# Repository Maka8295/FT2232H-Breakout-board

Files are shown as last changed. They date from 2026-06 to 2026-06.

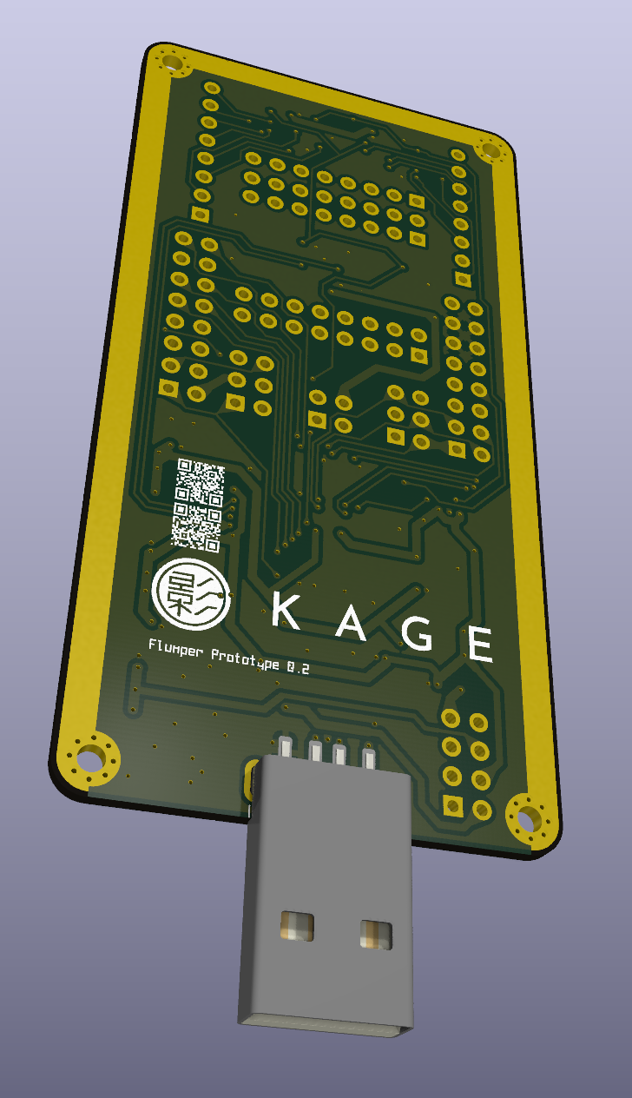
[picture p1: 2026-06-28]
flash2.png

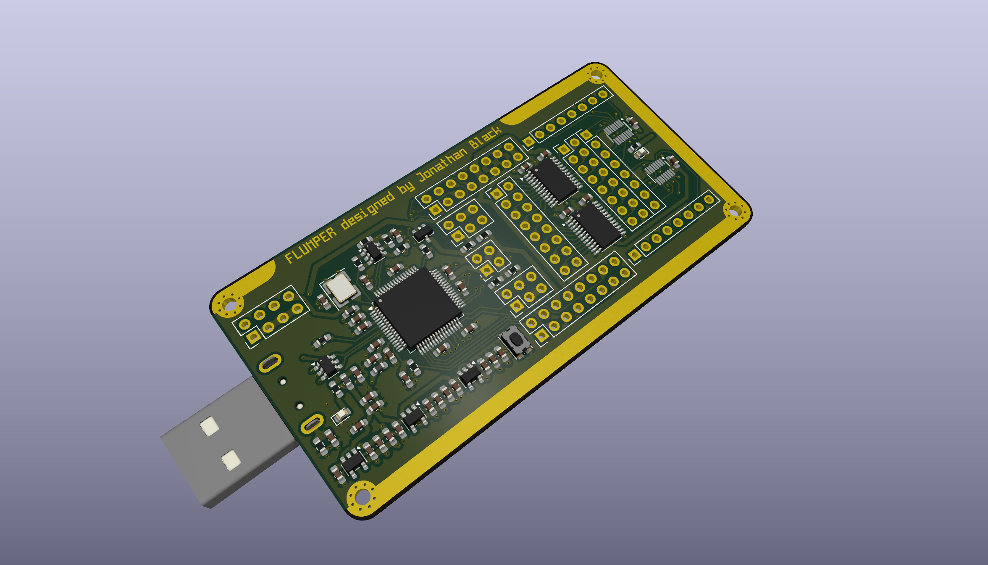
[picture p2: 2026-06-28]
flash.png

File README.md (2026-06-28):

# Bill of Materials

**Line items:** 28  |  **Total components:** 70

> Pin header connectors (J2–J12) are excluded from this BOM.

## IC

| Designator | Value / Part | Footprint | Qty |
|---|---|---|---|
| U1 | LDK130M18R | `SOT-23-5` | 1 |
| U2 | LDK130M25R | `SOT-23-5` | 1 |
| U3 | AP2112K-3.3 | `SOT-23-5` | 1 |
| U4 | USBLC6-2SC6 | `SOT-23-6` | 1 |
| U5 | 93LCxxBxxOT | `SOT-23-6` | 1 |
| U6 | FT2232HL | `LQFP-64_10x10mm_P0.5mm` | 1 |
| U7, U8 | TMUX1574DYY | `Texas_DYY0016A_TSOT-23-16_2x4.2mm_P0.5mm` | 2 |
| U9, U10 | SN74LVC8T245PWR | `TSSOP-24_4.4x7.8mm_P0.65mm` | 2 |

## Connector

| Designator | Value / Part | Footprint | Qty |
|---|---|---|---|
| J1 | USB_A | `USB_A_CNCTech_1001-011-01101_Horizontal` | 1 |

## Resistor

| Designator | Value / Part | Footprint | Qty |
|---|---|---|---|
| R1 | 2.2k | `R_0603_1608Metric_Pad0.98x0.95mm` | 1 |
| R2, R3, R5 | 1k | `R_0603_1608Metric_Pad0.98x0.95mm` | 3 |
| R4 | 1M | `R_0603_1608Metric_Pad0.98x0.95mm` | 1 |
| R6 | 12k/1% | `R_0603_1608Metric_Pad0.98x0.95mm` | 1 |
| R7, R8, R9, R10 | 4.7k | `R_0603_1608Metric_Pad0.98x0.95mm` | 4 |
| R11, R12, R13 | 10k | `R_0603_1608Metric_Pad0.98x0.95mm` | 3 |
| R14 | 2k | `R_0603_1608Metric_Pad0.98x0.95mm` | 1 |

## Capacitor

| Designator | Value / Part | Footprint | Qty |
|---|---|---|---|
| C1, C2, C3, C4, C5, C6 | 1uF | `C_0603_1608Metric_Pad1.08x0.95mm` | 6 |
| C7 | 2.2nF | `C_0603_1608Metric_Pad1.08x0.95mm` | 1 |
| C8, C10 | 10nF | `C_0603_1608Metric_Pad1.08x0.95mm` | 2 |
| C9 | 100nF | `C_0603_1608Metric_Pad1.08x0.95mm` | 1 |
| C11, C12, C13, C14, C15, C18, C19, C20, C22, C24, C27, C28, C29, C31, C33, C34, C35, C36, C37, C39 | 0.1uF | `C_0603_1608Metric_Pad1.08x0.95mm` | 20 |
| C16 | 0.01uF | `C_0603_1608Metric_Pad1.08x0.95mm` | 1 |
| C17, C21, C23, C30, C32, C38 | 4.7uF | `C_0603_1608Metric_Pad1.08x0.95mm` | 6 |

## Inductor

| Designator | Value / Part | Footprint | Qty |
|---|---|---|---|
| L1, L2, L3 | 600R/0.5A | `L_0603_1608Metric_Pad1.05x0.95mm` | 3 |

## Transistor/MOSFET

| Designator | Value / Part | Footprint | Qty |
|---|---|---|---|
| Q1 | AO3400A | `SOT-23` | 1 |

## LED

| Designator | Value / Part | Footprint | Qty |
|---|---|---|---|
| D1, D2 | LED | `LED_0603_1608Metric` | 2 |

## Crystal

| Designator | Value / Part | Footprint | Qty |
|---|---|---|---|
| Y1 | SCTF SX3M12.000M20F30TNN | `Crystal_SMD_3225-4Pin_3.2x2.5mm_HandSoldering` | 1 |

## Switch

| Designator | Value / Part | Footprint | Qty |
|---|---|---|---|
| SW1 | Reset Button | `SW_Push_1P1T_NO_CK_KMR2` | 1 |

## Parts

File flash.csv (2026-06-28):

Id | Designator | Footprint | Quantity | Designation | Supplier and ref
1 | C1, C2, C3, C4, C5, C6 | C_0603_1608Metric_Pad1.08x0.95mm_HandSolder | 6 | 1uF
2 | C7 | C_0603_1608Metric_Pad1.08x0.95mm_HandSolder | 1 | 2.2nF
3 | C8, C10 | C_0603_1608Metric_Pad1.08x0.95mm_HandSolder | 2 | 10nF
4 | C9 | C_0603_1608Metric_Pad1.08x0.95mm_HandSolder | 1 | 100nF
5 | C11, C12, C13, C14, C15, C18, C19, C20, C22, C24, C27, C28, C29, C31, C33, C34, C35, C36, C37, C39 | C_0603_1608Metric_Pad1.08x0.95mm_HandSolder | 20 | 0.1uF
6 | C16 | C_0603_1608Metric_Pad1.08x0.95mm_HandSolder | 1 | 0.01uF
7 | C17, C21, C23, C30, C32, C38 | C_0603_1608Metric_Pad1.08x0.95mm_HandSolder | 6 | 4.7uF
8 | D1, D2 | LED_0603_1608Metric | 2 | LED
9 | J1 | USB_A_CNCTech_1001-011-01101_Horizontal | 1 | USB_A
10 | J2 | PinHeader_2x04_P2.54mm_Vertical | 1 | Conn_01x08_Pin
11 | J3, J4 | PinHeader_2x03_P2.54mm_Vertical | 2 | Conn_01x06_Pin
12 | J5 | PinHeader_2x02_P2.54mm_Vertical | 1 | Conn_01x04_Pin
13 | J6 | PinHeader_2x08_P2.54mm_Vertical | 1 | AOUT
14 | J7 | PinHeader_2x08_P2.54mm_Vertical | 1 | BOUT
15 | J8 | PinHeader_2x08_P2.54mm_Vertical | 1 | LSIN
16 | J9 | PinHeader_2x08_P2.54mm_Vertical | 1 | LSOUT
17 | J10 | PinHeader_1x08_P2.54mm_Vertical | 1 | TMIN
18 | J11 | PinHeader_1x08_P2.54mm_Vertical | 1 | TM1OUT
19 | J12 | PinHeader_1x08_P2.54mm_Vertical | 1 | TM2OUT
20 | L1, L2, L3 | L_0603_1608Metric_Pad1.05x0.95mm_HandSolder | 3 | 600R/0.5A
21 | Q1 | SOT-23 | 1 | AO3400A
22 | R1 | R_0603_1608Metric_Pad0.98x0.95mm_HandSolder | 1 | 2.2k
23 | R2, R3, R5 | R_0603_1608Metric_Pad0.98x0.95mm_HandSolder | 3 | 1k
24 | R4 | R_0603_1608Metric_Pad0.98x0.95mm_HandSolder | 1 | 1M
25 | R6 | R_0603_1608Metric_Pad0.98x0.95mm_HandSolder | 1 | 12k/1%
26 | R7, R8, R9, R10 | R_0603_1608Metric_Pad0.98x0.95mm_HandSolder | 4 | 4.7k
27 | R11, R12, R13 | R_0603_1608Metric_Pad0.98x0.95mm_HandSolder | 3 | 10k
28 | R14 | R_0603_1608Metric_Pad0.98x0.95mm_HandSolder | 1 | 2k
29 | SW1 | SW_Push_1P1T_NO_CK_KMR2 | 1 | Reset Button
30 | U1 | SOT-23-5 | 1 | LDK130M18R
31 | U2 | SOT-23-5 | 1 | LDK130M25R
32 | U3 | SOT-23-5 | 1 | AP2112K-3.3
33 | U4 | SOT-23-6 | 1 | USBLC6-2SC6
34 | U5 | SOT-23-6 | 1 | 93LCxxBxxOT
35 | U6 | LQFP-64_10x10mm_P0.5mm | 1 | FT2232HL
36 | U7, U8 | Texas_DYY0016A_TSOT-23-16_2x4.2mm_P0.5mm | 2 | TMUX1574DYY
37 | U9, U10 | TSSOP-24_4.4x7.8mm_P0.65mm | 2 | SN74LVC8T245PWR
38 | Y1 | Crystal_SMD_3225-4Pin_3.2x2.5mm_HandSoldering | 1 | SCTF SX3M12.000M20F30TNN

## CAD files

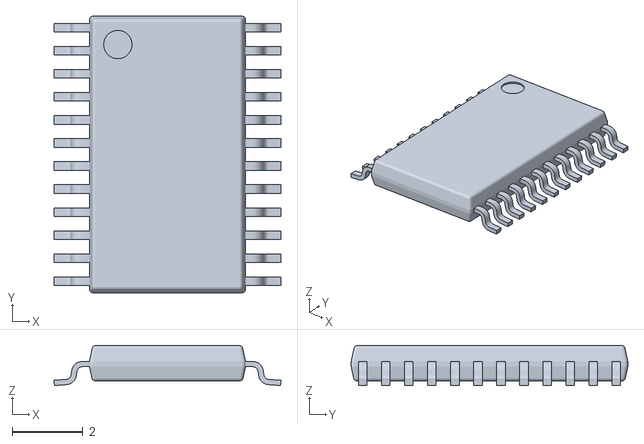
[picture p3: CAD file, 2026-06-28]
components/PW0024A.stl
6.40 x 7.80 x 1.13

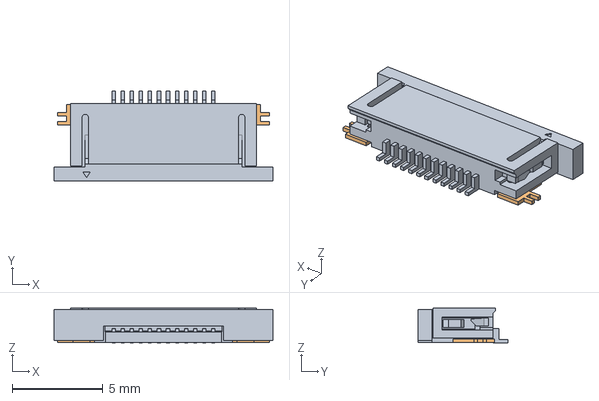
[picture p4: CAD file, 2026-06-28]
components/527461270.stp
12.1 x 5.00 x 1.92 mm

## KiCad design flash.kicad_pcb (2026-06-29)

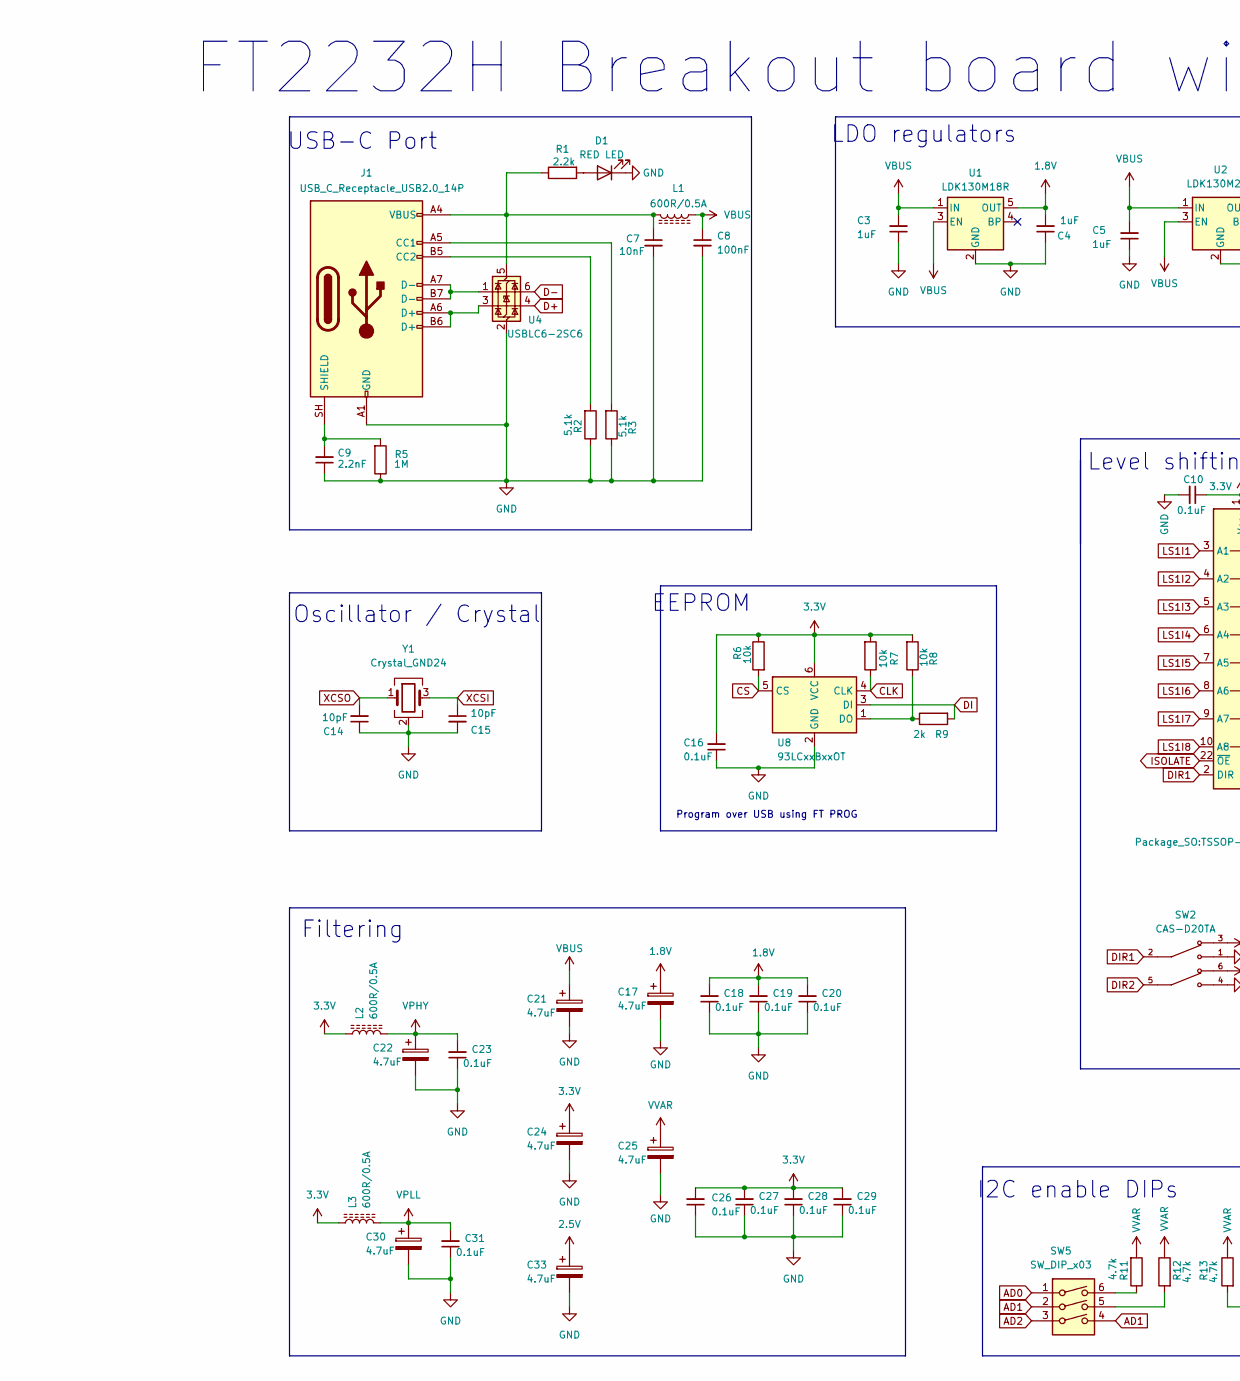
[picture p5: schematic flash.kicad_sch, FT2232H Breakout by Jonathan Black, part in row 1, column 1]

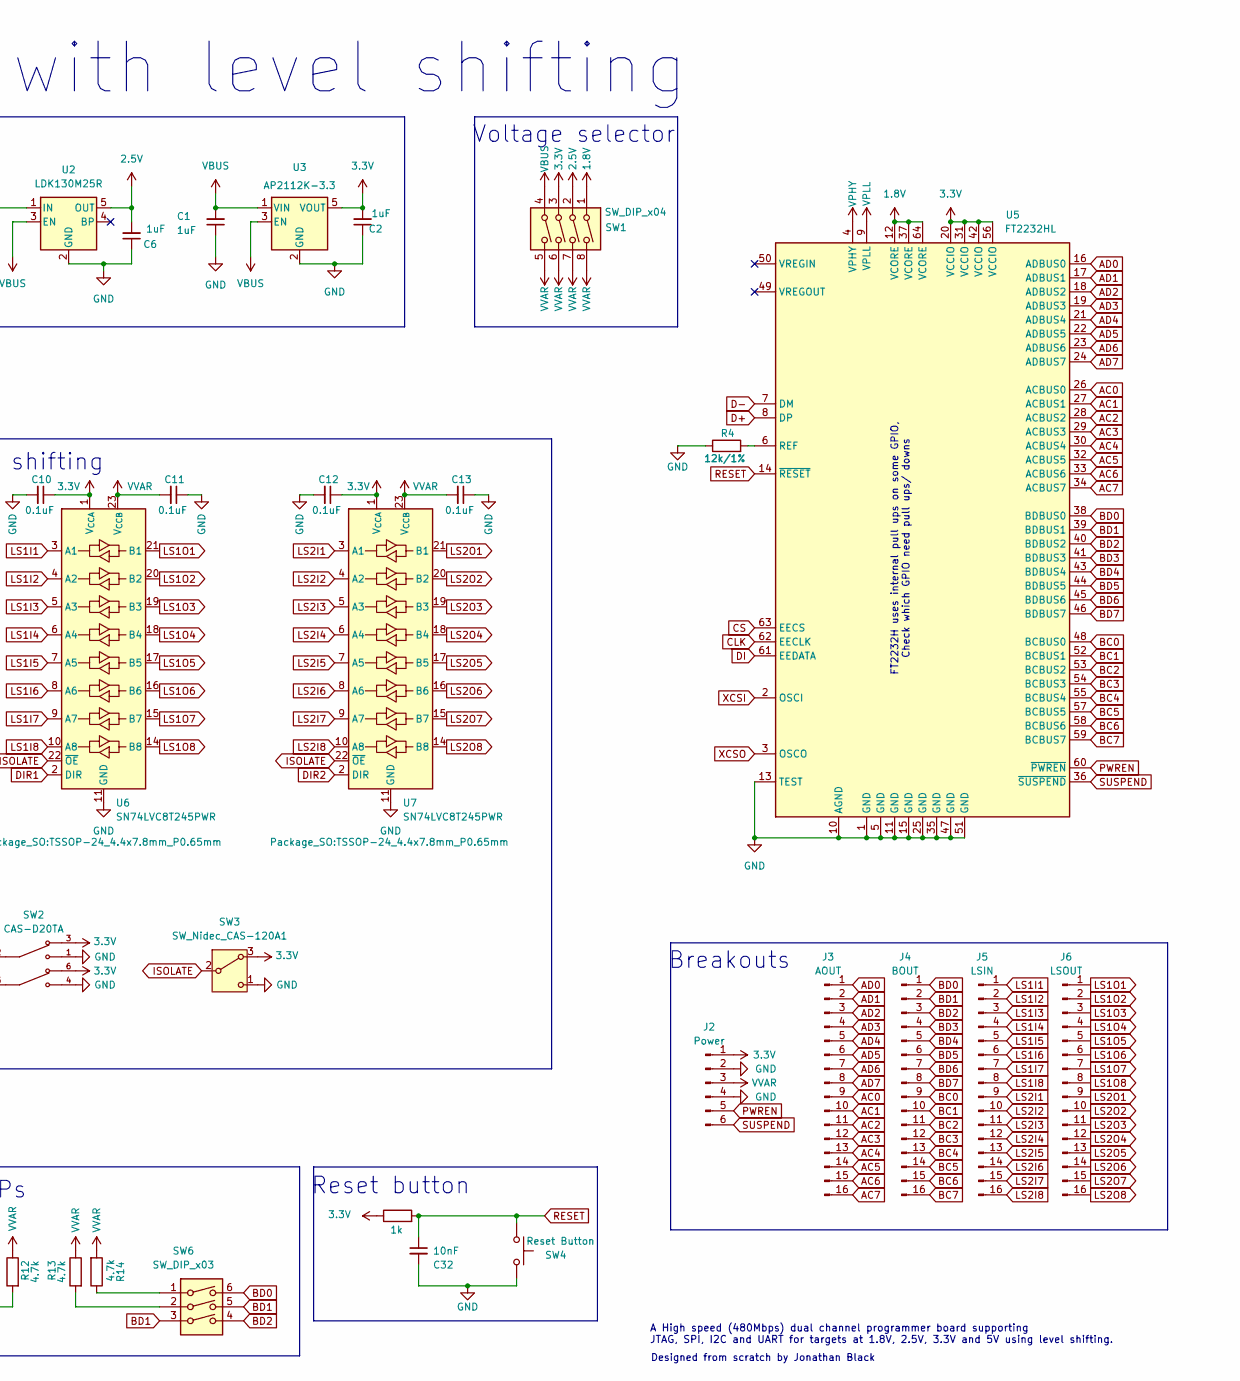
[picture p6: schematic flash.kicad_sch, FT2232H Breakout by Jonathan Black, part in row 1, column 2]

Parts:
C1, C2, C3, C4, C5, C6: 1uF; C_0603_1608Metric_Pad1.08x0.95mm_HandSolder
C7, C32: 10nF; C_0603_1608Metric_Pad1.08x0.95mm_HandSolder
C8: 100nF; C_0603_1608Metric_Pad1.08x0.95mm_HandSolder
C9: 2.2nF; C_0603_1608Metric_Pad1.08x0.95mm_HandSolder
C10, C11, C12, C13, C16, C18, C19, C20, C23, C26, C27, C28, C29, C31: 0.1uF; C_0603_1608Metric_Pad1.08x0.95mm_HandSolder
C14, C15: 10pF; C_0603_1608Metric_Pad1.08x0.95mm_HandSolder
C17, C21, C22, C24, C25, C30, C33: 4.7uF; C_0603_1608Metric_Pad1.08x0.95mm_HandSolder
D1: RED LED; LED_0603_1608Metric
J1: USB_C_Receptacle_USB2.0_14P; USB_C_Receptacle_HRO_TYPE-C-31-M-12
J2: Power; PinHeader_2x03_P2.54mm_Vertical
J3: AOUT; PinHeader_1x16_P2.54mm_Vertical
J4: BOUT; PinHeader_1x16_P2.54mm_Vertical
J5: LSIN; PinHeader_2x08_P2.54mm_Vertical
J6: LSOUT; PinHeader_2x08_P2.54mm_Vertical
L1, L2, L3: 600R/0.5A; L_0603_1608Metric_Pad1.05x0.95mm_HandSolder
R1: 2.2k; R_0603_1608Metric_Pad0.98x0.95mm_HandSolder
R2, R3: 5.1k; R_0603_1608Metric_Pad0.98x0.95mm_HandSolder
R4: 12k/1%; R_0603_1608Metric_Pad0.98x0.95mm_HandSolder
R5: 1M; R_0603_1608Metric_Pad0.98x0.95mm_HandSolder
R6, R7, R8: 10k; R_0603_1608Metric_Pad0.98x0.95mm_HandSolder
R9: 2k; R_0603_1608Metric_Pad0.98x0.95mm_HandSolder
R10: 1k; R_0603_1608Metric_Pad0.98x0.95mm_HandSolder
R11, R12, R13, R14: 4.7k; R_0603_1608Metric_Pad0.98x0.95mm_HandSolder
SW1: SW_DIP_x04; SW_DIP_SPSTx04_Slide_Copal_CHS-04A_W5.08mm_P1.27mm_JPin
SW2: CAS-D20TA; SW_CAS-D20TA; PARTREV N/A
SW3: SW_Nidec_CAS-120A1; Nidec_Copal_CAS-120A
SW4: Reset Button; SW_Push_1P1T_NO_CK_KMR2
SW5, SW6: SW_DIP_x03; SW_DIP_SPSTx03_Slide_KingTek_DSHP03TJ_W5.25mm_P1.27mm_JPin
U1: LDK130M18R; SOT-23-5
U2: LDK130M25R; SOT-23-5
U3: AP2112K-3.3; SOT-23-5
U4: USBLC6-2SC6; SOT-23-6
U5: FT2232HL; LQFP-64_10x10mm_P0.5mm
U6, U7: SN74LVC8T245PWR; TSSOP-24_4.4x7.8mm_P0.65mm
U8: 93LCxxBxxOT; SOT-23-6
Y1: Crystal_GND24; Crystal_SMD_3225-4Pin_3.2x2.5mm_HandSoldering

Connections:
1.8V: C4.2, C17.1, C18.2, C19.2, C20.2, SW1.1, U1.5 (OUT), U5.12 (VCORE), U5.37 (VCORE), U5.64 (VCORE)
2.5V: C6.2, C33.1, SW1.2, U2.5 (OUT)
3.3V: C2.2, C10.1, C12.1, C16.2, C24.1, C26.2, C27.2, C28.2, C29.2, J2.1, L2.1, L3.1, R6.1, R7.2, R8.2, R10.1, SW1.3, SW2.3, SW2.6, SW3.3 (A), U3.5 (VOUT), U5.20 (VCCIO), U5.31 (VCCIO), U5.42 (VCCIO), U5.56 (VCCIO), U6.1 (V_{CCA}), U7.1 (V_{CCA}), U8.6 (VCC)
AC0: J3.9, U5.26 (ACBUS0)
AC1: J3.10, U5.27 (ACBUS1)
AC2: J3.11, U5.28 (ACBUS2)
AC3: J3.12, U5.29 (ACBUS3)
AC4: J3.13, U5.30 (ACBUS4)
AC5: J3.14, U5.32 (ACBUS5)
AC6: J3.15, U5.33 (ACBUS6)
AC7: J3.16, U5.34 (ACBUS7)
AD0: J3.1, SW5.1, U5.16 (ADBUS0)
AD1: J3.2, SW5.2, SW5.4, U5.17 (ADBUS1)
AD2: J3.3, SW5.3, U5.18 (ADBUS2)
AD3: J3.4, U5.19 (ADBUS3)
AD4: J3.5, U5.21 (ADBUS4)
AD5: J3.6, U5.22 (ADBUS5)
AD6: J3.7, U5.23 (ADBUS6)
AD7: J3.8, U5.24 (ADBUS7)
BC0: J4.9, U5.48 (BCBUS0)
BC1: J4.10, U5.52 (BCBUS1)
BC2: J4.11, U5.53 (BCBUS2)
BC3: J4.12, U5.54 (BCBUS3)
BC4: J4.13, U5.55 (BCBUS4)
BC5: J4.14, U5.57 (BCBUS5)
BC6: J4.15, U5.58 (BCBUS6)
BC7: J4.16, U5.59 (BCBUS7)
BD0: J4.1, SW6.6, U5.38 (BDBUS0)
BD1: J4.2, SW6.3, SW6.5, U5.39 (BDBUS1)
BD2: J4.3, SW6.4, U5.40 (BDBUS2)
BD3: J4.4, U5.41 (BDBUS3)
BD4: J4.5, U5.43 (BDBUS4)
BD5: J4.6, U5.44 (BDBUS5)
BD6: J4.7, U5.45 (BDBUS6)
BD7: J4.8, U5.46 (BDBUS7)
CLK: R7.1, U5.62 (EECLK), U8.4 (CLK)
CS: R6.2, U5.63 (EECS), U8.5 (CS)
D+: U4.4 (I/O2), U5.8 (DP)
D-: U4.6 (I/O1), U5.7 (DM)
DI: R9.2, U5.61 (EEDATA), U8.3 (DI)
DIR1: SW2.2, U6.2 (DIR)
DIR2: SW2.5, U7.2 (DIR)
GND: C1.1, C2.1, C3.1, C4.1, C5.1, C6.1, C7.2, C8.2, C9.1, C10.2, C11.1, C12.2, C13.1, C14.1, C15.2, C16.1, C17.2, C18.1, C19.1, C20.1, C21.2, C22.2, C23.1, C24.2, C25.2, C26.1, C27.1, C28.1, C29.1, C30.2, C31.1, C32.2, C33.2, D1.1 (K), J1.A1 (GND), J1.A12 (GND), J1.B1 (GND), J1.B12 (GND), J2.2, J2.4, R2.1, R3.1, R4.1, R5.1, SW2.1, SW2.4, SW3.1 (C), SW4.2, U1.2 (GND), U2.2 (GND), U3.2 (GND), U4.2 (GND), U5.1 (GND), U5.5 (GND), U5.10 (AGND), U5.11 (GND), U5.13 (TEST), U5.15 (GND), U5.25 (GND), U5.35 (GND), U5.47 (GND), U5.51 (GND), U6.11 (GND), U6.12 (GND), U6.13 (GND), U7.11 (GND), U7.12 (GND), U7.13 (GND), U8.2 (GND), Y1.2 (G), Y1.4 (G)
ISOLATE: SW3.2 (B), U6.22 (~OE), U7.22 (~OE)
LS1I1: J5.1, U6.3 (A1)
LS1I2: J5.2, U6.4 (A2)
LS1I3: J5.3, U6.5 (A3)
LS1I4: J5.4, U6.6 (A4)
LS1I5: J5.5, U6.7 (A5)
LS1I6: J5.6, U6.8 (A6)
LS1I7: J5.7, U6.9 (A7)
LS1I8: J5.8, U6.10 (A8)
LS1O1: J6.1, U6.21 (B1)
LS1O2: J6.2, U6.20 (B2)
LS1O3: J6.3, U6.19 (B3)
LS1O4: J6.4, U6.18 (B4)
LS1O5: J6.5, U6.17 (B5)
LS1O6: J6.6, U6.16 (B6)
LS1O7: J6.7, U6.15 (B7)
LS1O8: J6.8, U6.14 (B8)
LS2I1: J5.9, U7.3 (A1)
LS2I2: J5.10, U7.4 (A2)
LS2I3: J5.11, U7.5 (A3)
LS2I4: J5.12, U7.6 (A4)
LS2I5: J5.13, U7.7 (A5)
LS2I6: J5.14, U7.8 (A6)
LS2I7: J5.15, U7.9 (A7)
LS2I8: J5.16, U7.10 (A8)
LS2O1: J6.9, U7.21 (B1)
LS2O2: J6.10, U7.20 (B2)
LS2O3: J6.11, U7.19 (B3)
LS2O4: J6.12, U7.18 (B4)
LS2O5: J6.13, U7.17 (B5)
LS2O6: J6.14, U7.16 (B6)
LS2O7: J6.15, U7.15 (B7)
LS2O8: J6.16, U7.14 (B8)
unnamed: D1.2 (A), R1.2
unnamed: J1.A5 (CC1), R3.2
unnamed: J1.B5 (CC2), R2.2
unnamed: J1.A6 (D+), J1.B6 (D+), U4.3 (I/O2)
unnamed: J1.A7 (D-), J1.B7 (D-), U4.1 (I/O1)
unnamed: C9.2, J1.SH (SHIELD), R5.2
unnamed: R11.1, SW5.6
unnamed: R12.2, SW5.5
unnamed: R13.2, SW6.2
unnamed: R14.1, SW6.1
unnamed: C7.1, J1.A4 (VBUS), J1.A9 (VBUS), J1.B4 (VBUS), J1.B9 (VBUS), L1.2, R1.1, U4.5 (VBUS)
unnamed: R4.2, U5.6 (REF)
unnamed: R8.1, R9.1, U8.1 (DO)
PWREN: J2.5, U5.60 (~PWREN)
RESET: C32.1, R10.2, SW4.1, U5.14 (~RESET)
SUSPEND: J2.6, U5.36 (~SUSPEND)
VBUS: C1.2, C3.2, C5.2, C8.1, C21.1, L1.1, SW1.4, U1.1 (IN), U1.3 (EN), U2.1 (IN), U2.3 (EN), U3.1 (VIN), U3.3 (EN)
VPHY: C22.1, C23.2, L2.2, U5.4 (VPHY)
VPLL: C30.1, C31.2, L3.2, U5.9 (VPLL)
VVAR: C11.2, C13.2, C25.1, J2.3, R11.2, R12.1, R13.1, R14.2, SW1.5, SW1.6, SW1.7, SW1.8, U6.23 (V_{CCB}), U6.24 (V_{CCB}), U7.23 (V_{CCB}), U7.24 (V_{CCB})
XCSI: C15.1, U5.2 (OSCI), Y1.3
XCSO: C14.2, U5.3 (OSCO), Y1.1

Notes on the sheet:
Breakouts
Level shifting
Reset button
I2C enable DIPs
FT2232H Breakout board with level shifting
FT2232H uses internal pull ups on some GPIO, Check which GPIO need pull ups/ downs
Designed from scratch by Jonathan Black
Filtering
USB-C Port
Voltage selector
Program over USB using FT PROG
A High speed (480Mbps) dual channel programmer board supporting JTAG, SPI, I2C and UART for targets at 1.8V, 2.5V, 3.3V and 5V using level shifting.
Oscillator / Crystal
EEPROM
LDO regulators

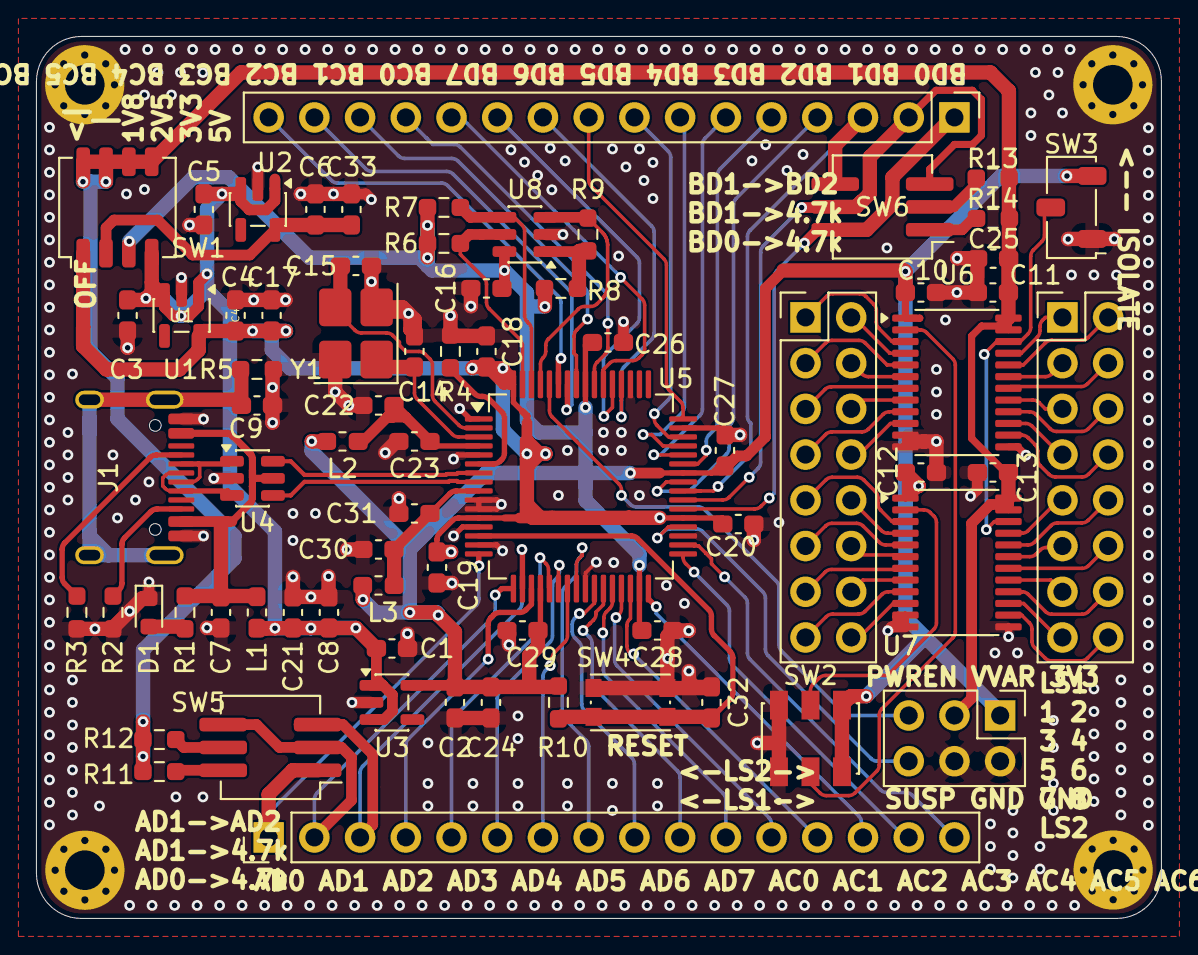
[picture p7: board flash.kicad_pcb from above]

Board: 4 copper layers, 62.5 x 49.0 mm, 72 parts (0 on the bottom side), 98 nets.
